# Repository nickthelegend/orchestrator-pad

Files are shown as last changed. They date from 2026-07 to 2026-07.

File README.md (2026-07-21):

<div align="center">

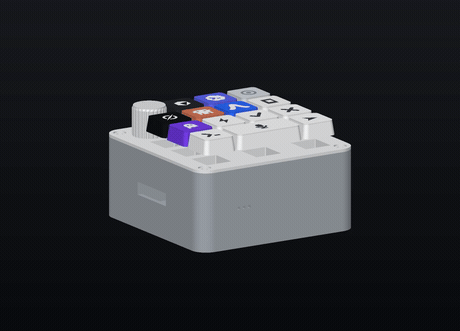
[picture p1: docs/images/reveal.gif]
Orchestrator Pad — assembled, exploding into its layers, and back together


<sub>tray · switch deck · plate · keycaps · knob — [watch the 15s MP4](docs/orchestrator-pad-reveal.mp4)</sub>

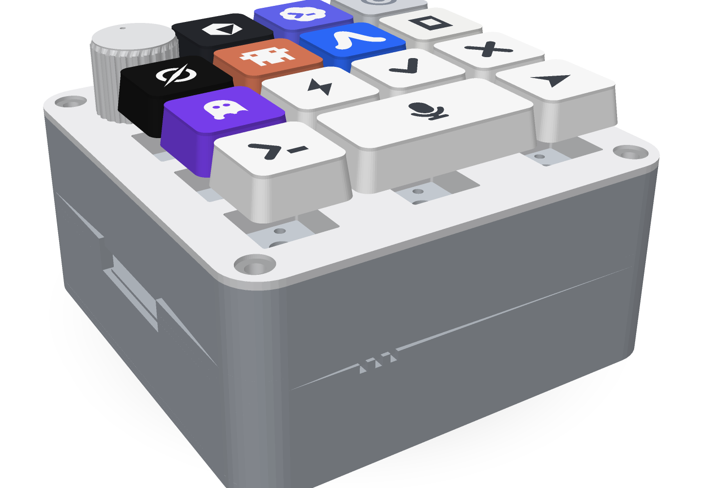
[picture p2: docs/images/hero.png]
Orchestrator Pad — 3D-printed macropad with agent keys, voice bar and effort dial


# Orchestrator Pad

**A desk controller for your coding agents.**
Lock an agent with one key. Hold the bar and talk. Twist the dial to set how hard the model thinks.







[Print it](#print-it) · [What's inside](#whats-inside) · [How a job flows](#how-a-job-flows) · [The CAD is code](#the-cad-is-code) · [Roadmap](#roadmap)

</div>

---

Pointing five different CLI agents at your projects means five terminals and a
lot of retyping. The Orchestrator Pad is a small (~90 × 90 mm) open-source
macropad that turns the routing into muscle memory: **one key per agent, one
bar for your voice, one dial for effort** — from `low` all the way up to
`ultracode`. It speaks Wi-Fi to your orchestrator daemon, with USB-HID as the
fallback.

Everything here is remixable: the enclosure is parametric Python, the agents
on the caps are just a table in `cad/partlib.py`, and the whole thing prints
on a bed-slinger in an evening.

## The deck

<div align="center">
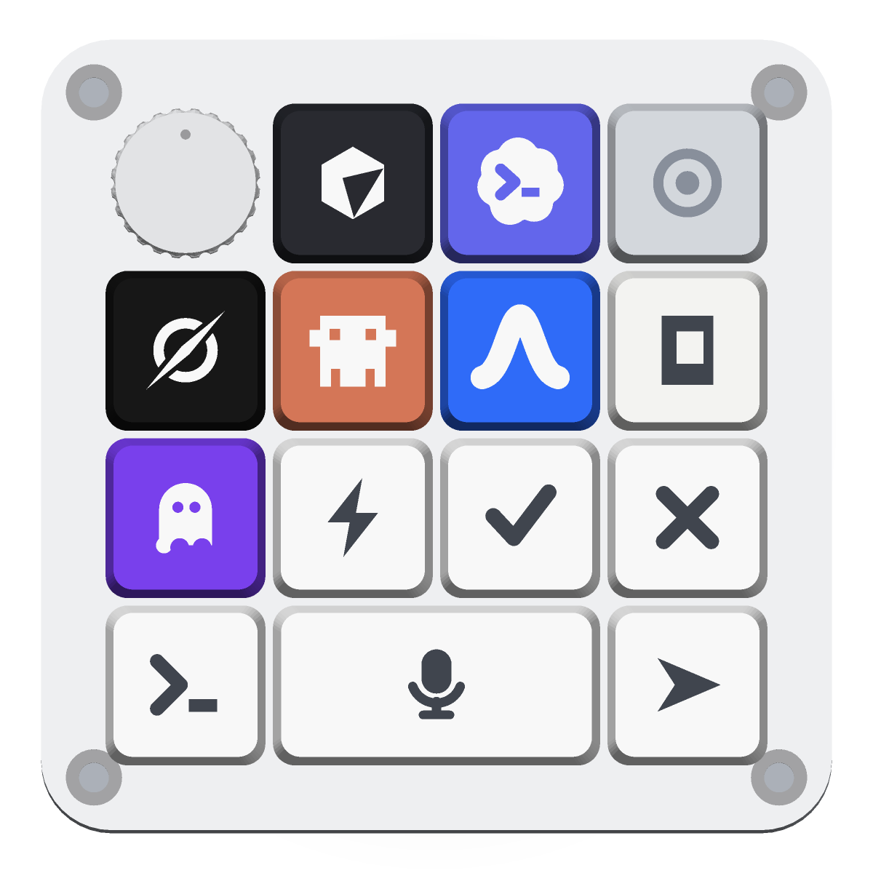
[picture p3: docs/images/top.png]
Top view — key layout

</div>

| | Key | Cap | What it does |
|---|---|---|---|
| 🎛 | **Effort dial** | knurled knob | detents map to `low → medium → high → xhigh → max → ultracode` |
| ⬜ | **Cursor** | cube-facet logo | lock jobs to Cursor |
| 🟣 | **Codex** | cloud `>_` logo | lock jobs to Codex |
| ⚪ | Preset | `◎` | saved context / status (RGB glow optional) |
| ⬛ | **Grok** | circle-slash logo | lock jobs to Grok |
| 🟧 | **Claude Code** | pixel-pal logo | lock jobs to Claude |
| 🟦 | **Antigravity** | arch logo | lock jobs to Antigravity |
| ⬜ | **opencode** | terminal-frame logo | lock jobs to OpenCode |
| 🟪 | **Kiro** | ghost logo | lock jobs to Kiro |
| ⚡ | Run | `⚡` | kick off the queued job |
| ✓ | Approve | `✓` | accept a plan / permission prompt |
| ✕ | Reject | `✕` | decline / cancel |
| ⟩_ | Prompt | `⟩_` | focus the target session's terminal |
| 🎤 | **Voice bar (2u)** | `🎤` | **hold to talk** — audio streams to the daemon for speech-to-text |
| ➤ | Send | `➤` | dispatch to the locked agent at the dialed effort |

Every glyph is debossed 0.6 mm **and** ships with a matching legend infill
piece, so the logos print in a contrast color (white on the colored caps,
charcoal on the white ones) — no more squinting.

## How a job flows

```
hold 🎤 ──► ESP32-S3 streams mic audio ──► daemon does STT
release ──► { agent: "claude", effort: "ultracode", prompt: "..." }
press ➤ ──► daemon routes the job to the locked agent's session
   ✓ / ✕ ──► answer the agent's next approval prompt from the pad
```

The pad itself stays dumb on purpose: it emits a tiny JSON protocol
(`{agent, action, effort, audio?}`) over WebSocket and lets the daemon own
speech-to-text, session routing, and CLI orchestration. Point it at your own
stack by implementing one message handler.

## Make it talk — firmware + backend

The hardware above is the enclosure; these two pieces bring it to life. This
first build is **hold-to-talk over Wi-Fi, no dial** (no potentiometer): press an
agent key to lock that agent, hold the mic key and speak, hear the agent answer.

```
[ pad ]  select agent ─▶ POST /select        [ backend on your Mac ]     [ Loom daemon ]
         hold-to-talk ─▶ POST /voice (PCM) ─▶  STT → agent → TTS  ◀──────▶  handoff + message
              amp     ◀─ 16 kHz PCM reply   ◀─                             (visible in the thread)
```

**Wiring** — the 4×4 matrix, INMP441 mic, and MAX98357A amp + speaker on an ESP32-S3 (full pin-by-pin tables in the [firmware README](firmware/README.md#hardware--wiring)):

<div align="center">
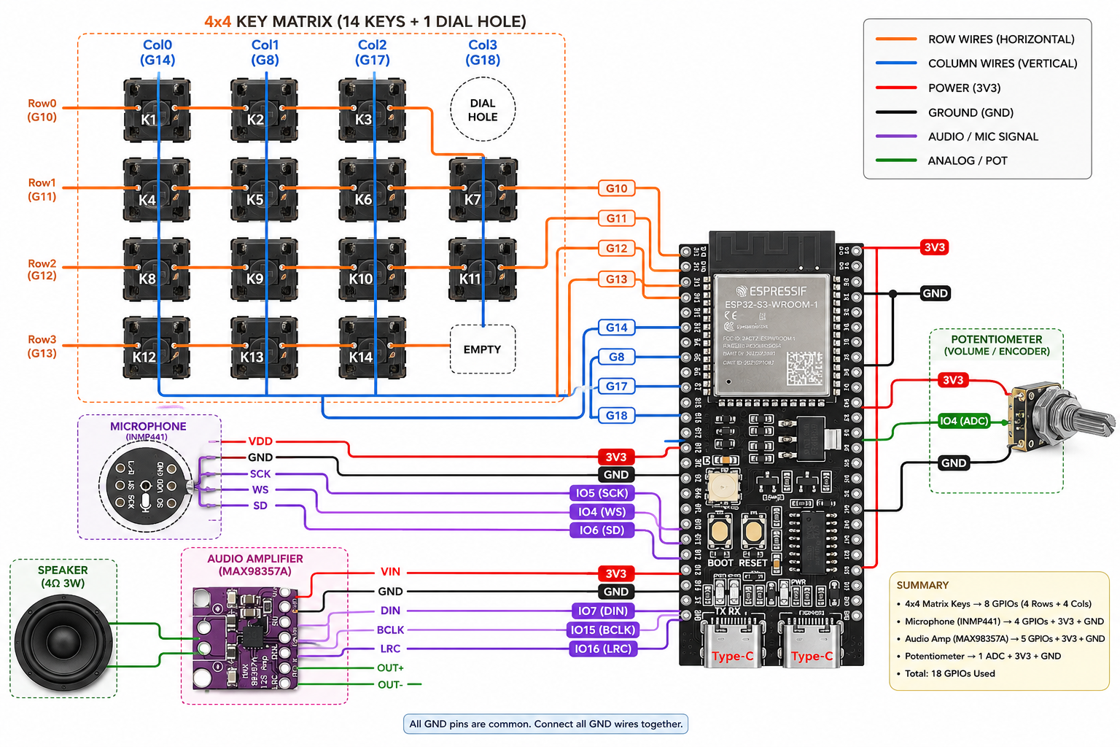
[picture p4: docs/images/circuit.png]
Orchestrator Pad wiring diagram — 4×4 key matrix, INMP441 mic, MAX98357A amp and speaker, on an ESP32-S3-WROOM-1

</div>

- **[`firmware/`](firmware)** — ESP32-S3 sketch: captive-portal Wi-Fi setup
  (`LoomPad-Setup`), agent-select keys, hold-to-talk mic streaming, and a telnet
  debug console. Wiring, key map, and flashing steps in the
  [firmware README](firmware/README.md).
- **[`backend/`](backend)** — a zero-dependency Node server that runs on your Mac
  (Groq STT + LLM, Deepgram TTS) and bridges the pad to the Loom daemon. Two API
  keys, `npm start`, done — see the [backend README](backend/README.md).

**Bring it up:** `cd backend && cp .env.example .env` (add two keys) → `npm start`
→ flash the firmware → join `LoomPad-Setup` and enter your backend URL (a LAN
`http://<mac-ip>:8080`, or a `https://…ts.net` Tailscale Funnel for anywhere) →
press an agent key, hold the mic, talk.

## Print it

<div align="center">
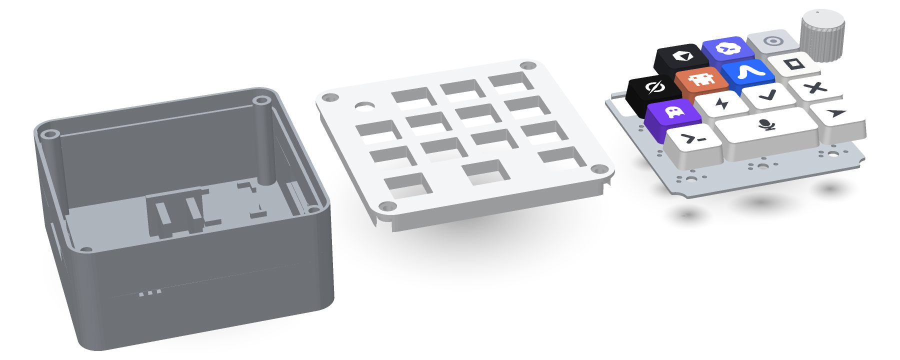
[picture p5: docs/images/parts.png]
Printable parts — tray, plate, keycaps, knob

</div>

| Part | File | Orientation | Supports |
|---|---|---|---|
| Tray (bottom) | [`exports/tray.stl`](exports/tray.stl) | as exported, flat on bed | none |
| Plate (top) | [`exports/plate.stl`](exports/plate.stl) | **flip 180°** — top face on bed | none |
| Switch deck | [`exports/switch-deck.stl`](exports/switch-deck.stl) | as exported, flat on bed | none |
| Keycaps ×14 | [`exports/caps-all.stl`](exports/caps-all.stl) | **flip 180°** — cap tops on bed | none |
| Legend infills ×14 | [`exports/legends-all.stl`](exports/legends-all.stl) | import **with** caps-all, flip together | none |
| Dial knob | [`exports/knob.stl`](exports/knob.stl) | as exported (crown-down) | none |

0.4 mm nozzle · 0.2 mm layers · PETG or PLA. Slow the first layer and outer
walls for crisp glyphs. Each STL is a union of individually watertight
shells — every mainstream slicer merges them automatically.

**Two-color legends:** import `caps-all` + `legends-all` in one plate (they're
pre-aligned), flip 180° together, and assign the legend object a contrast
filament (AMS/MMU). Flipped, the legends are the **first 3 layers on the
bed**, so even a single-extruder printer can do it with one manual filament
swap at layer 4. No multi-color setup? Print caps alone and paint-fill the
recesses — they're 0.6 mm deep on purpose.

**Switch sockets — solder like it's a PCB:**

<div align="center">
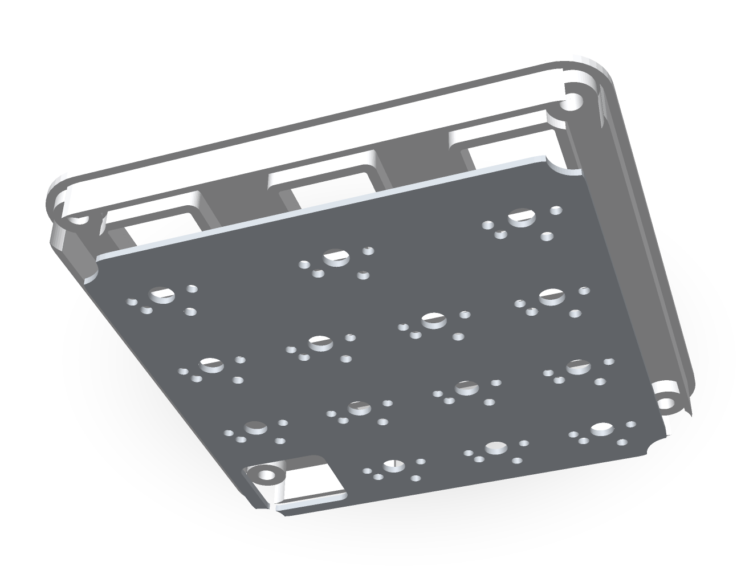
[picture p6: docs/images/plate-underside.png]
Plate underside — donor-keyboard-style switch sockets with MX footprint floors

</div>

Donor-keyboard-style mounting, engineered to print clean: the plate's
underside has a socket well caging every switch body, and the footprints
live on a separate **switch deck** — one flat sheet with all 14 MX clusters
(center-post hole + the two slanted contact holes + 5-pin legs). Because the
deck prints flat on the bed, every hole is perfectly round and the flipped
plate is pure vertical walls — **no bridges, no floating regions, no
supports on either part**.

Assembly: clip the switches into the plate, then press the deck up onto
them from below — it friction-fits on the center posts and 5-pin legs and
seats against the socket-wall rims. The metal pins stick out **2.1 mm**
through the deck: flow solder on, run your matrix wire, done.

**The dial is a mock — it just clips in.** No potentiometer in this build, so
the knob has a snap-fit peg instead of an encoder bore: push it through the
plate's Ø7.4 hole and it clicks under the plate and **spins freely** — a
display dial you can twist for the demo. The plate is unchanged, so it's a
knob-only reprint.

<div align="center">
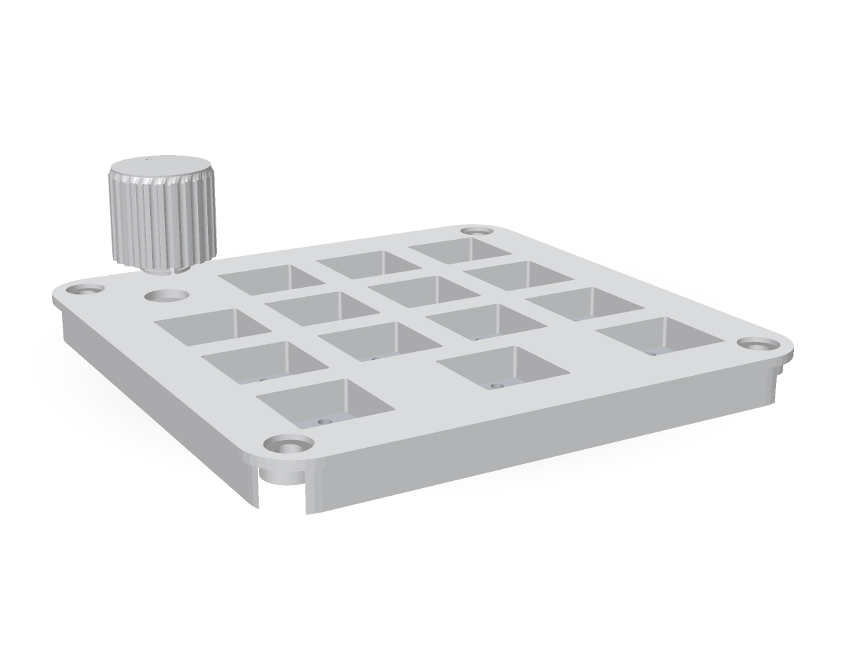
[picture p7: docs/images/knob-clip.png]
Mock knob with snap-fit peg clipping into the plate's dial hole

</div>

Tolerances assume a reasonably tuned printer; every clearance is a named
constant in [`SPEC.md`](SPEC.md) if yours runs tight.

## What's inside

<div align="center">
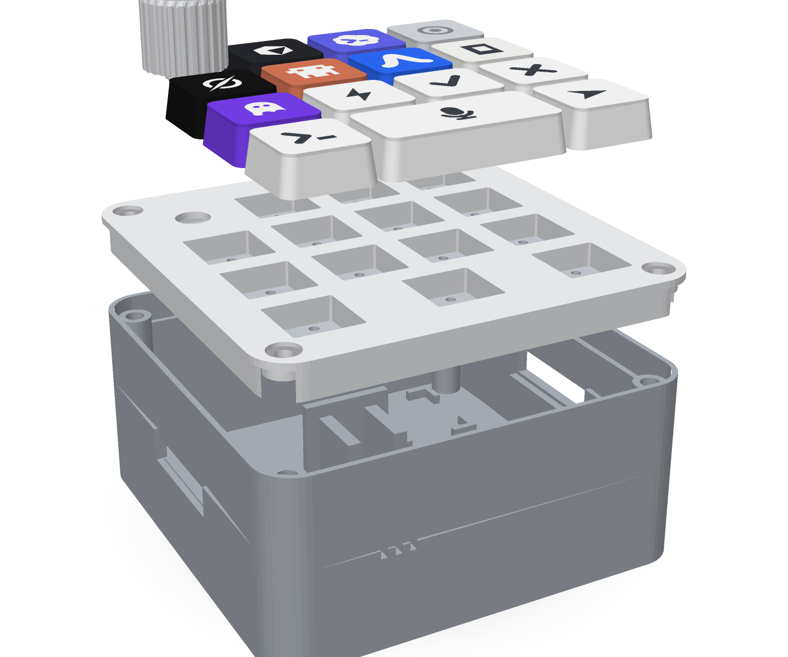
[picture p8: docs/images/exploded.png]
Exploded view

</div>

| Qty | Part | Notes |
|---|---|---|
| 1 | **ESP32-S3 dev board** (WROOM-1, dual USB-C clones welcome) | factory pin headers are fine — the board rides flat shelves + ribs (no posts in the way), with ~24 mm of open headroom above it; install it ports-**right** or ports-**left** (both side walls have a window) |
| 14 | MX-style switches (3-pin plate-mount, donor-board pulls work) | 13 × 1u + 1 for the 2u voice bar; they clip into the plate's square holes exactly like a stock keyboard plate |
| 1 | **4Ω 3W cavity speaker**, flange up to 72 × 42 mm | down-firing bay in the floor: grille slots + 4 × M2.5 self-tapper pilots |
| 1 | **MAX98357A I2S amp** breakout | drops into the corner pocket, foam-tape mounted |
| 1 | I2S MEMS microphone (INMP441 class, round or square) | glues behind the front mic grille |
| 1 | EC11 rotary encoder | M7 bush mounts in the plate; 15 mm D-shaft; the knob hides the nut |
| 4 | M3 heat-set inserts + **M3×8** button-head screws | tray bosses ← plate counterbores |
| 4 | rubber feet, **≥3 mm tall** | give the down-firing speaker its air gap |
| — | zip ties, jumper wires | a flat wire bar with zip-tie slots is printed into the tray (no posts in the way) |
| — | optional: WS2812 LEDs | under the preset key |

<div align="center">
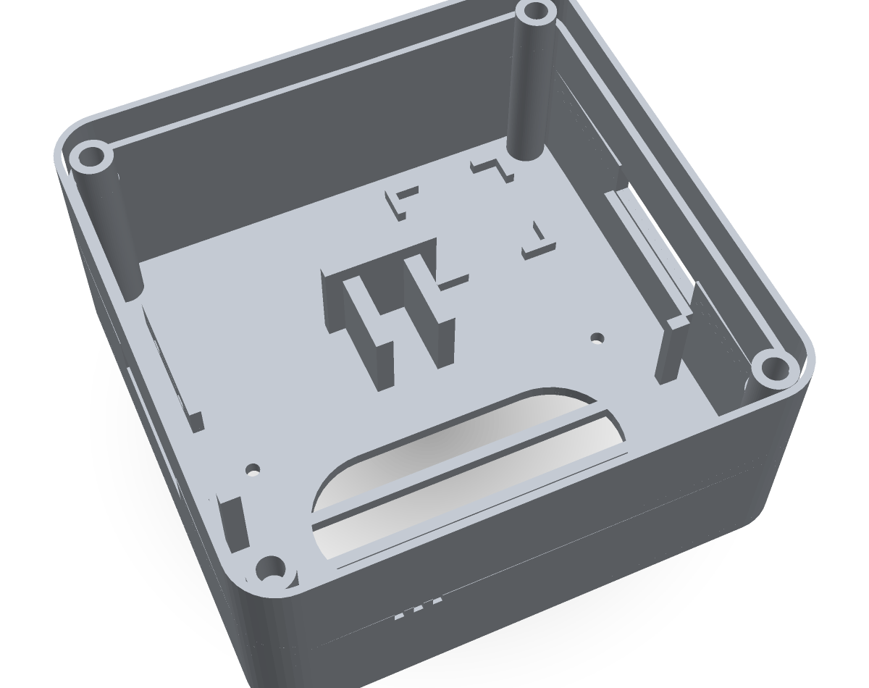
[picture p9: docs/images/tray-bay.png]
Tray interior — reversible board bay, speaker grille, amp pocket, wire posts

</div>

**Cable exits either side.** The board lies across the case with its USB-C
edge against a side wall, and both side walls carry a window — so you install
it **ports-right or ports-left** depending on which way your desk wants the
cable. The unused window becomes a wire pass-through for the speaker or amp
harness.

Assembly: heat-set the four inserts, screw the speaker over the floor grille,
foam-tape the amp into its pocket, rest the board on the shelves + ribs
(components up, USB out whichever side window you picked), clip the switches into the plate,
hand-wire the matrix, glue the mic behind the grille, zip-tie the slack to the
posts, screw the sandwich together, press on caps and knob. A strip of kapton
over the board is cheap insurance under the switch pins.

## The CAD is code

No STEP files, no Fusion — the entire enclosure is generated by
[`cad/partlib.py`](cad/partlib.py), a ~500-line kernel that extrudes 2D
`shapely` profiles into watertight shells (**zero 3D CSG**, so there's nothing
to corrupt), plus one script per part. Change a constant, rerun, reprint:

```bash
python3 -m venv .venv && .venv/bin/pip install numpy shapely
cd cad
../.venv/bin/python assembly.py      # STLs + GLBs + MANIFEST.json
../.venv/bin/python render_docs.py   # re-render the README images (numpy only)
```

<details>
<summary><b>Design notes & receipts</b></summary>

- Every part is validated for closed, manifold, positive-volume shells on
  every build (`partlib.validate`) — the manifest records the results.
- The fit audits in `cad/audit_*.py` are re-runnable: they check switch
  cutouts, screw stacks, cap clearances, and the DevKitC seating against
  **Espressif's official board drawing** — which is how we caught that the
  DevKitC-1's USB ports sit 7.79 mm off the board centerline. The case slot
  is centered on the *native/OTG* port, not the board.
- Keycaps use a hollow tapered loft with a printed MX cross stem and 0.6 mm
  debossed glyphs built as layered shells — no boolean subtraction anywhere.
- `exports/orchestrator-pad-assembled.glb` and `-exploded.glb` are the full
  colored models — drop them into any glTF viewer.

</details>

## Roadmap

- [x] v1 printable enclosure, caps, knob — parametric CAD + audited fit (branch [`v1`](../../tree/v1))
- [x] v2 logo keycaps (Claude Code · Antigravity · opencode · Kiro · Cursor), taller case for full DevKitC clearance, USB mating relief (branch [`v2`](../../tree/v2))
- [x] v3 — Grok + Codex keys (seven agents), two-color legend infills (`legends-all.stl`) (branch [`v3`](../../tree/v3))
- [x] v4 — the fat base: 28 mm component bay with a down-firing speaker bay, amp pocket, board bridge with header-pin clearance, dual-USB-C window, and zip-tie wire posts
- [x] v5 — donor-style switch sockets + the flat-printed **switch deck** (footprint sheet, pins protrude 2.1 mm for direct soldering; zero bridges/supports on the plate) (branch [`v5`](../../tree/v5))
- [x] v6 — USB moved to the **side walls**: the board bay is rotated and reversible, so the cable exits right or left (branch [`v6`](../../tree/v6))
- [x] **v7 (current)** — **fatter**: 40 mm case with ~24 mm of open headroom above the board, and the cylindrical locator/wire posts replaced with flat guide rails + zip-tie slots (nothing free-standing in the bay)
- [ ] `firmware/` — ESP-IDF: matrix scan, encoder detents, hold-to-talk ring
      buffer, WebSocket client, USB-HID fallback
- [ ] daemon reference handler + pairing flow
- [ ] hand-wire guide with photos
- [ ] PCB with hotswap sockets + WS2812
- [ ] translucent-PETG preset keys with light pipes

PRs welcome — the fastest way to help is to print one and file issues with
your tolerance notes.

## License

[MIT](LICENSE). The agent names and logo-inspired cap glyphs refer to
third-party projects — the marks belong to their respective owners; the
glyphs here are simplified geometric homages for personal builds.

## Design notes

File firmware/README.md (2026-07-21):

# Orchestrator Pad — firmware

ESP32-S3 firmware for the hold-to-talk build. Select an agent with a key, hold
the mic key and talk, hear the agent answer — all over Wi-Fi to the
[backend](../backend) on your Mac. Wi-Fi and the backend address are set once
through a captive portal and remembered in flash; **no recompile to change
networks**, and **no potentiometer on this build** (the effort dial is omitted).

Sketch: [`orchestrator_pad/orchestrator_pad.ino`](orchestrator_pad/orchestrator_pad.ino).

## What it does

1. **Provision** — first boot (or hold **K1** at power-on) raises a Wi-Fi
   access point, **`LoomPad-Setup`**. Join it from a phone/laptop; a captive
   page lists nearby networks and asks for the **backend URL** and a **pad
   token**. Save → the pad joins your Wi-Fi and stores everything in NVS.
2. **Connect** — it starts a telnet debug server, checks the backend's
   `/health`, and asks the backend to **speak "connected"** through the amp.
3. **Run** — an agent key locks that agent in Loom (a handoff, visible in the
   thread) and lights the LED its colour. Hold **K1** to record; release to send
   the audio to that agent and play its spoken reply.

## Hardware & wiring

ESP32-S3-DevKitC-1 (N16R8 — 16 MB flash / 8 MB PSRAM). No pot, no diodes.

<div align="center">
Orchestrator Pad wiring diagram — 4×4 key matrix, INMP441 mic, MAX98357A amp + speaker, on an ESP32-S3-WROOM-1
</div>

The full wiring at a glance: the 4×4 matrix (rows `G10–G13`, columns
`G14/G8/G17/G18`), the INMP441 mic and MAX98357A amp on I2S, and the (optional)
pot. The tables below are the same thing, cell by cell — all grounds are common.

**Mic — INMP441 (I2S RX):** `VDD→3V3`, `GND→GND`, `L/R→GND`

| INMP441 | SCK | WS | SD |
|---|---|---|---|
| GPIO | **5** | **4** | **6** |

**Amp — MAX98357A (I2S TX):** `Vin→3V3`, `GND→GND`, `SD→3V3` (leave SD high to enable)

| MAX98357A | BCLK | LRC | DIN |
|---|---|---|---|
| GPIO | **15** | **16** | **7** |

**4×4 key matrix** (rows are `INPUT_PULLUP`, columns driven low one at a time —
no diodes needed):

| | Col0 | Col1 | Col2 | Col3 |
|---|---|---|---|---|
| **Rows →** | GPIO 14 | GPIO 8 | GPIO 17 | GPIO 18 |
| Row0 · GPIO 10 | **K1 mic** | K2 | K3 | — |
| Row1 · GPIO 11 | K4 | K5 | K6 | K7 |
| Row2 · GPIO 12 | K8 | K9 | K10 | K11 |
| Row3 · GPIO 13 | K12 | K13 | K14 | — |

**Status LED:** onboard WS2812 on **GPIO 48**.

All pins live in [`orchestrator_pad/config.h`](orchestrator_pad/config.h) — change
them there if your wiring differs.

## Key map

Edit [`orchestrator_pad/agents.h`](orchestrator_pad/agents.h) to match your
keycaps. As shipped:

| Key | Role | Agent | LED |
|---|---|---|---|
| **K1** | 🎤 hold to talk | — | red while recording |
| K2 | agent | `claude-code` | amber |
| K3 | agent | `opencode` | teal |
| K4 | agent | `codex` | green |
| K5 | agent | `grok-code` | white |
| K6 | agent | `antigravity` | blue |
| K7 | agent | `kiro` | purple |

K8–K14 are spare. K1 doubles as the **re-provision** key: hold it at power-on to
wipe saved Wi-Fi and re-open the portal.

### Status-LED colours

| Colour | Meaning |
|---|---|
| blue | booting |
| cyan / magenta | connecting / setup portal open |
| green | connected & ready |
| agent colour | that agent is selected (idle) |
| red | recording (or an error) |
| amber | thinking (waiting on the reply) |

## Flashing

**Libraries** (Arduino IDE → Library Manager):

- **WiFiManager** by *tzapu* — the captive portal.
- `ESP_I2S`, `WiFi`, `HTTPClient`, `Preferences` ship with the **arduino-esp32
  core 3.x** — nothing to install, but you do need core 3.x (Boards Manager →
  "esp32" by Espressif, ≥ 3.0).

**Board settings** (Tools menu) — the three starred ones matter:

- Board: **ESP32S3 Dev Module**
- ⭐ **PSRAM: `OPI PSRAM`** — the record buffer is `ps_malloc`'d; without this it
  fails to allocate and the mic won't record.
- ⭐ **USB CDC On Boot: `Enabled`** — so the Serial monitor works over USB-C.
- ⭐ **Partition Scheme: `Huge APP (3MB No OTA/1MB SPIFFS)`** — the TLS stack
  pushes the build to ~90 % of the *default* 1.3 MB app partition (it fits, but
  barely). Huge APP drops it to ~37 %. Flash Size: `16MB`.

> Verified: this compiles clean against **esp32 core 3.3.10 + WiFiManager 2.0.17**
> for `esp32s3` (OPI PSRAM, USB-CDC) — 1.18 MB flash, 48 KB RAM, no warnings in
> the sketch.

**Steps:**

1. Open [`orchestrator_pad/orchestrator_pad.ino`](orchestrator_pad/orchestrator_pad.ino).
2. Install WiFiManager, set the board options above, pick the port, **Upload**.
3. First boot: join the **`LoomPad-Setup`** Wi-Fi from your phone. If the portal
   doesn't pop up, browse to `http://192.168.4.1`.
4. Pick your Wi-Fi, enter the **backend URL** and **pad token** (below), save.
5. It joins, says "connected," and you're ready: **press an agent key, then hold
   K1 to talk.**

### Backend URL & token

One field decides where — and how — the pad reaches the backend; the **scheme
picks the transport**:

| You're… | Enter | Token |
|---|---|---|
| on the same Wi-Fi as the Mac | `http://<mac-lan-ip>:8080` (e.g. `http://192.168.1.20:8080`) | blank is fine on a trusted LAN |
| anywhere / the pad moves around | `https://<machine>.<tailnet>.ts.net` (Tailscale Funnel) | **required** — Funnel is public |

- **`http://…`** → plain connection. Use the Mac's **LAN IP**, *not* its
  `tailscale ip` (`100.x`) — a bare ESP32 can't route to a tailnet address.
- **`https://…ts.net`** → TLS, with the Let's Encrypt root pinned (the pad
  verifies the cert, so the token can't be MITM'd). Set the same `PAD_TOKEN` on
  the backend. See the [backend README](../backend/README.md#pointing-the-pad-at-it)
  for the one-time `tailscale funnel 8080` setup.

Change either later without reflashing: `reset-wifi` over telnet (or hold **K1**
at power-on) re-opens the portal.

## Telnet debug

The S3's USB-CDC serial can be flaky, so the pad mirrors its logs to a telnet
server and takes commands back — no cable needed:

```
telnet <pad-ip> 23
```

| Command | Does |
|---|---|
| `help` | list commands |
| `status` | Wi-Fi / IP / RSSI / heap / PSRAM / backend / selected agent |
| `ip` · `heap` · `agent` | quick reads |
| `select <agent>` | lock an agent (same as pressing its key) |
| `say <text>` | speak text through the amp (tests the backend + amp) |
| `talk` | hands-free: record ~4 s and send (tests the mic without a key) |
| `reset-wifi` | wipe Wi-Fi + settings and reboot into the portal |
| `reboot` | restart |

`say hello` and `talk` are the fastest way to prove the audio path end to end.

## Troubleshooting

| Symptom | Fix |
|---|---|
| No serial output | Set **USB CDC On Boot: Enabled**, re-upload |
| "PSRAM alloc failed" in the log | Set **PSRAM: OPI PSRAM** |
| "backend not reachable" | Backend running? Right URL? On `http://`, use the Mac's **LAN IP** not `100.x`. Fix with `reset-wifi` |
| Works on LAN, fails on the `ts.net` URL | Is `tailscale funnel` running? Does `PAD_TOKEN` match on both sides? (a 401 means the token's wrong/blank) |
| Portal never opens | Forget/rejoin `LoomPad-Setup`, or browse to `192.168.4.1` |
| Amp silent | Check `DIN/BCLK/LRC` wiring and that the amp's **SD pin is tied to 3V3** |
| Mic captures nothing | Check `SCK/WS/SD`, and tie the INMP441 **L/R pin to GND** |
| Keys wrong / swapped | Fix the pin arrays in `config.h` and the grid in `agents.h` |

See the [backend README](../backend) for the server it talks to.

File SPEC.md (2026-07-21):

# Orchestrator Pad — dimensional spec (v7)

Open-source ESP32 macropad for orchestrating coding agents: lock a target agent
(Grok / Codex / Claude Code / Antigravity / opencode / Kiro / Cursor),
hold-to-talk voice capture, and a dial that sets model effort
(`low → medium → high → xhigh → max → ultracode`).

All dimensions in **mm**. Axes: X right, Y back (away from user), Z up.
Origin: center of the case footprint, Z=0 at the tray's outer bottom face.

## Layout (19.05 mm grid, 4 columns x 4 rows)

Column centers X: -28.575, -9.525, +9.525, +28.575 (cols 0..3)
Row centers Y: +28.575, +9.525, -9.525, -28.575 (rows 0..3, row 0 = back/top)

| Pos | What | Glyph (debossed) |
|---|---|---|
| r0c0 | EC11 rotary encoder (effort dial) | knurled knob, tick dot |
| r0c1 | agent key: Cursor | `cursor` (cube, raised facet) |
| r0c2 | agent key: Codex | `codex` (cloud, raised `>_`) |
| r0c3 | preset/status key (translucent look) | `target` |
| r1c0..c3 | agent keys: Grok, Claude Code, Antigravity, opencode | `grok` (circle-slash), `claude` (pixel-pal), `antigravity` (arch), `opencode` (frame) |
| r2c0 | agent key: Kiro | `kiro` (ghost) |
| r2c1..c3 | run / approve / reject | `bolt`, `check`, `cross` |
| r3c0 | prompt/terminal key | `prompt` |
| r3 c1–c2 | **voice bar, 2u** (hold-to-talk), centered at X=0 | `mic` |
| r3c3 | send/dispatch key | `send` |

Total: **14 MX switches** (13 x 1u + 1 x 2u), 1 EC11 encoder.

## Case (two printed shells + knob + caps)

### Tray (bottom shell) — `part_tray.py`
- Outer: 90.0 x 90.0, corner R8, height **40.0** (v7 fat/tall base — +12 over
  v6's 28.0, for lots of open headroom above the board; the interior is a
  component bay). Wall 2.4, floor 2.4.
- Ledge for the top's skirt: below Z=33.5 wall is 2.4 thick; above Z=33.5 the
  inner face steps out so wall is **1.2** thick (skirt seat).
- 4 corner bosses Ø7.0 at (±39, ±39) — **round** (M3 heat-set inserts thread
  in): solid pedestal from floor top (Z2.4) to **Z=31.5**, insert ring
  Ø7.0/Ø4.0 to **Z=37.5** (bore 6.0 deep from the top, floor at Z 31.5 — M3
  heat-set insert). The bosses now run floor→37.5 (through the raised ledge).
- **USB windows**, BOTH side walls (X=+45 and X=-45): each **26.0 wide** in
  Y centered Y=0, **Z 17.0..23.5**, through BOTH wall columns. The board
  turns 90° so its ports face a side wall, and the bay is **reversible** —
  the board installs **ports-right or ports-left**, and the *unused* window
  is documented as a **wire pass-through** (run the speaker/mic/amp harness
  or a USB extension out of it). The board's dual side-by-side USB-C ports
  sit on its TOP face (shells 8.94 x 3.3 → Z 17.6..20.9, center 19.25) and
  exit through whichever window they face; each window is wide + tall enough
  that exact port offsets don't matter (shells stay inside for port centers
  |y| ≤ 8.53, a 12-wide plug hood for |y| ≤ 7.0), and the receptacle face
  sits only ~1.7 behind the outer wall — under the ~2.5 of exposed plug
  shroud, so any hood works at the aperture mouth. v7 raised the ledge to
  33.5, so each window top (23.5) now sits **entirely below the ledge** —
  both wall columns close the window with a solid cap at 23.5 and run solid
  to their tops (liner→33.5, outer→40.0), and the **plate skirt no longer
  needs a USB notch**. The two side cuts split each cut wall band into a back
  arc and a front arc — every piece is still its own watertight prism, fused
  to the solid ring bands above and below by the 0.2 lap.
- **Board bay (rotated + REVERSIBLE)** — dual-USB-C ESP32-S3 clone,
  components UP, factory header pins DOWN, laid **along X**: up to **64.0
  long (X) x 30.0 wide (Y)**, centered Y=0 (|y| ≤ 15). Two installs, both
  seating identically because every bay feature is mirror-symmetric about
  X=0:
  - **ports-right** X **-22.0 … +42.0** (USB-C exits the X=+45 window)
  - **ports-left**  X **-42.0 … +22.0** (USB-C exits the X=-45 window)
  - side shelves (BOTH walls): tabs protruding 1.6 from each side wall's
    inner face (42.6), spanning **|x| 41.0..42.8** (0.2 lap into the liner)
    and **|y| ≤ 14.0**, body Z 13.5..16.0 — the board's port edge seats on
    one and its far edge overhangs the other; **Z=16.0** top faces (1.0
    bearing, 0.6 edge-to-wall gap on the port side).
  - mid-span ribs: two walls at **X +4.0..+7.0** and **X -7.0..-4.0**,
    **Y +1.0..+16.0**, floor to **Z=16.0** — they carry the board's middle
    (~112 mm² of total seat bearing per orientation). They stay at Y ≥ +1.0
    on purpose: the speaker flange occupies X ±36, Y -42..0, and a rib
    crossing it would foul the flange (1.0 clear as drawn).
  - **board cage (FLAT — NO cylindrical posts, v7)**: the board is caged in
    Y by flat guide walls only, placed only in speaker-clear zones (the
    flange is X ±36, Y -42..0; supports live at Y>0 or |X|>36). Inner faces
    at |y| = 15.1 → 0.1 clearance per side to a 30-wide board, tops **Z=19.0**
    (1.4 lip over the board top at 17.6). Mirror-symmetric about X=0:
    - **back guide rail**: a flat wall, inner face **Y=+15.1**, outer
      **Y=+17.1** (2.0 thick), spanning **X -10.0..+10.0**, floor→Z=19.0 —
      caps the board's +Y edge. (Nominal span was X ±34, but the amp
      L-ridges reach X 10.5 inside the rail's Y band 15.1..17.1, so the rail
      is trimmed to **±10.0** to clear the amp by 0.5 while staying
      symmetric and watertight; it fuses with the two mid-span ribs at
      Y 15.1..16 by design, tying it to the load-bearing ribs.)
    - **front corner tabs**: two flat tabs, inner face **Y=-15.1**, outer
      **Y=-17.1**, spanning **X 36.8..40.0** and **X -40.0..-36.8** (both at
      |X|>36, clear of the flange edge at 36 by 0.8), floor→Z=19.0 — they
      guide the board's front-edge corners in whichever orientation reaches
      that side.
    Together with the flat mid-span ribs and dual side shelves (all
    retained, unchanged), the board is caged in Y from both edges while
    nothing ever crosses the speaker flange.
  - under-board clearance floor→16.0 = **13.6 mm** for the soldered header
    pins (~8.5 under the PCB) + angled dupont connectors. Headers now run
    along the board's long edges (y = ±15). Wire in the open pockets either
    side of the ribs. Pin tails that land over a rib (X ±4..7, Y +1..+16)
    must be clipped flush; over the speaker zone (Y < 0) the driver bump can
    rise to Z 14.9 under the pin rows — clip there too, or verify your
    speaker's bump footprint. (Headers usually stop ~2 mm short of the
    board ends, clearing the 1.0 shelf lip.)
- **Speaker bay** (down-firing, flange ON the floor, centered (0, -21)):
  - floor opening: racetrack (rounded-rect R12) **54 x 24** at (0, -21) with
    two 2.0-wide grille bars along X → 3 slots (~6.7 each), through both
    floor layers.
  - 4 screw pilots Ø2.4 THROUGH the floor at (±31.5, -37.5) and
    (±31.5, -4.5) — the 63 x 33 pattern. M2.5 x 6 self-tappers from inside:
    heads on the flange, tips end 2.1 under the floor, inside the ≥3 mm
    foot gap. The two back pilots' bottom rims merge ~1.0 into the front
    feet-recess rims (0.6 recess layer only) — stick those feet biased
    outward.
  - fits flanges up to **72 x 42** (a sharp-cornered 72 x 42 grazes the two
    front bosses by ~0.5; real cavity flanges with corner R ≥ 6.5 clear —
    **measure yours**) and driver bumps up to **Ø50 x 11 tall** (oval, ≤
    50 x 40 in plan): bump top 2.4 + 1.5 + 11 = **14.9** clears the board
    underside at 16.0 by 1.1. **Measure the bump height — the bay assumes
    ≤ 11.**
- **Amp pocket**: four L-corner ridges (1.5 wide, 2.0 tall, 6-long legs)
  framing a 20 x 20 pocket centered **(+22, +27)** — the MAX98357A drops in,
  foam-tape mounted. It sits on the back strip, out from under the rotated
  board: the ridges span X 10.5..33.5, Y 15.5..38.5, so the outer edge clears
  the board edge at Y 15.0 by **0.5** (both orientations), the corner bosses'
  inner face at X 35.5 by **2.0**, and the speaker by 15.5. v7 deleted the
  locator posts, so the pocket is now a **clean, full 20 x 20** (the old
  (+20, +17.6) post no longer clips its south edge); an ~18 x 16 breakout
  drops in with ~1.0/side play. The nearest cage wall is the back rail,
  trimmed to ±10 so it clears the amp by 0.5.
- **Wire bar** (FLAT — replaces the v6 wire posts, NO cylinders): a low flat
  wall along the west interior, inner face **X=-36.0**, outer **X=-38.0**
  (2.0 thick), spanning **Y +6.0..+30.0**, floor→**Z=8.0**, with **two
  3.2-wide x 2.0-tall through-slots** (band-split in Z, at Z 3.0..5.0)
  centered **Y=+12** and **Y=+24**. A zip tie threads a slot and cinches the
  harness against the bar. It tops out at Z 8.0 — well below the left USB
  window (Z 17.0) — and Y 6..30 clears the speaker flange (Y≤0) by 6.0 and
  the (-39, +39) corner boss by 5.5. It underlies the ports-left board
  footprint in plan but sits 8.0 below the board underside (16.0), so it
  never obstructs board seating in either orientation.
- **Mic grille**, front wall (Y=-45): 3 x 1.5 square ports, spacing 3.0,
  centered X=-20, **Z 19.4..20.9** — far below the raised 33.5 ledge; the round
  I2S mic module glues behind them, above the speaker body. (Replaces v3's
  low-Z round ports.)
- Feet recesses: bottom face, 4 x Ø9.0 x 0.6 deep at (±36, ±36). Use
  **≥3 mm tall feet** so the down-firing speaker breathes (and the M2.5
  tips stay 0.3 off the desk).

### Top plate — `part_plate.py`
- Plate: 90.0 x 90.0, R8, **1.5 thick**, spans Z 40.0 → 41.5 (counterbore
  bands 40.0..40.7 + 40.5..41.5; case stack ~41.5 mm + caps/knob).
- 14 MX cutouts **14.1 x 14.1** (14.0 nominal + 0.1 print tolerance) at the
  grid positions above (2u voice = one switch centered at X=0, r3). These
  are exactly donor-keyboard-style plate holes — harvested 3-pin white MX
  clones clip straight into the 1.5 plate.
- **Switch sockets + deck (v5.1, donor-board style, print-clean)**: under
  every cutout a pocket box cages the switch body — walls 1.6 (outer 17.3
  sq) from **Z 36.5** (the MX base-seat plane, plate top − 5.0) up 0.2 into
  the plate. Flipped for printing, the plate is pure vertical walls: no
  bridges, no floating regions, no supports. The footprint floor is the
  separate **switch deck**: a 1.2-thick flat sheet (78 × 78 R6, Z
  35.3..36.5) carrying all 14 MX clusters — center post Ø**4.15** (snug on
  the Ø4.0 post), contact pin holes Ø**2.0** at (−3.81, +2.54) and
  (+2.54, +5.08), 5-pin leg holes Ø**1.85** (snug on Ø1.7) at (±5.08, 0);
  offsets from each key center, +Y toward the back. It prints FLAT
  (perfect holes), presses onto the switch posts/legs from below
  (friction-fit), seats against the socket-wall rims, has a 16 sq cutout
  under the EC11 body and Ø8.8 notches at the four screw towers (≥0.15,
  audited). The metal pins protrude **2.1** below the deck (tips Z 33.2):
  solder the matrix wires directly to them, PCB-style.
- Knob hole Ø**7.4** at r0c0 (EC11 M7 threaded bush).
- Skirt: ring 1.15 thick x 6.7 deep (Z 33.5 → 40.2), outer profile =
  87.3 x 87.3 R6.9 x-y, inner 85.0 x 85.0 R6.3 (drops inside the tray's
  87.6 upper 1.2 wall with ~0.15 clearance per side). Notched ONLY for the
  bosses now: **Ø8.6 corner clearances** at (±39, ±39) around the tray
  bosses (which rise to Z 37.5, through the skirt band). v7 raised the ledge
  to 33.5 while the USB windows still top out at 23.5 — the **side windows
  sit entirely below the ledge**, no longer cross into the skirt seat, so the
  **v6 side USB notches are gone**. The ring survives as **4 arc segments**
  (one per edge, severed at the 4 corner notches), each a watertight prism
  fused to plate band A. (The front mic notch is likewise unneeded: the mic
  grille at Z 19.4..20.9 sits far below the ledge.)
- 4 screw towers Ø7.6 from Z 37.5 → 40.2 at (±39, ±39), through-hole Ø3.4
  continuing through the plate, counterbore Ø6.4 x 0.8 from the top face
  (M3 x 8 button-head into the tray inserts).

### Keycaps — `part_caps.py`
- 1u: base 18.2 x 18.2 R2.5, top 16.4 x 16.4 R2.2, height **7.5** (loft taper),
  wall 1.6, hollow underneath.
- 2u voice bar: base 37.25 x 18.2, top 35.4 x 16.4, same height/wall.
- MX stem: post Ø5.8, length 3.9 below the cap ceiling; cross slots
  4.15 x 1.35, depth 3.9 (friction fit on MX stem).
- Glyphs debossed **0.6** into the top: build the top 0.8 mm of the cap as a
  layer with glyph-shaped holes; solid body below ends 0.6 lower, glyph
  islands (e.g. the pixel-pal's eyes) overlap 0.2 into the body below so every
  shell fuses when sliced.
- **Legend infills**: each glyph also exports as a separate flush 0.6 prism
  (`<id>-legend` items, merged into `exports/legends-all.stl`, same drop as
  `caps-all.stl` so both stay aligned). Print caps + legends together in two
  colors (AMS/MMU, or a manual filament swap on the last 3 layers when caps
  print top-face-down), or skip the file and paint-fill the recesses. Legend
  colors per key live in `partlib.key_layout()` (white on colored caps, dark
  gray on white caps).

### Knob — `part_knob.py` (v7.1 MOCK, no potentiometer)
- Ø17.0, height 15.0. Knurl: 24 flutes (Ø1.6 scallops on the rim).
- Top: 1.5 chamfer loft to Ø16.0, tick-dot deboss near edge.
- **Snap-fit peg** on the underside — no EC11 shaft: a Ø**7.2** tube split by
  1.2-wide cross-slots into 4 flex fingers, hollow Ø4.6 core, with a Ø**8.2**
  barb at the tip and a stepped lead-in chamfer. Push it through the plate's
  Ø7.4 hole: the fingers compress, the barb springs out under the plate. The
  knob body rests on the plate top (Z 41.5) and the barb catches the
  underside (ledge Z 39.8, **0.2 axial play** below the plate bottom) so it
  stays on **and spins freely** — a display dial for the demo. The plate is
  identical to an EC11 build; only this part differs. **Tuning:** if the snap
  is too tight, drop `BARB_D` to 8.0; too loose, raise to 8.4.
- Prints **crown-DOWN** (peg pointing up) — no supports.

## Assembly (`assembly.py`)
- Tray at Z0 → plate on top (plate top face Z=41.5).
- Caps: bottom face at **Z=47.0** (switch seated, cap floats ~5.5 over plate).
- Knob: bottom at **Z=41.5** over r0c0 (rests on the plate top; snap peg
  clips through the Ø7.4 hole and spins).
- Exports: `exports/orchestrator-pad-assembled.glb`, `exports/orchestrator-pad-exploded.glb`
  (tray +0 / plate +20 / caps +40 / knob +52), plus one STL per printable part
  (`tray`, `plate`, `caps-all`, `legends-all`, `knob`).

## Colors (GLB preview only)
tray `#AEB4BC`, plate `#F4F5F7`, preset cap `#D8DCE2`, Grok `#141414`,
Codex `#6366F1`, Claude Code `#D97757`, Antigravity `#2D6BFF`,
opencode `#FAFAF8`, Kiro `#7A3FF2`, Cursor `#26282E`,
run/approve/reject/prompt/send `#FFFFFF`, voice bar `#FFFFFF`, knob `#E8E9EB`.
Legends: white `#FFFFFF` on colored caps, dark `#3F444D` on white caps,
mid `#8A919E` on the preset.

Logo glyphs (`grok`, `codex`, `claude`, `antigravity`, `opencode`, `kiro`,
`cursor`) are simplified geometric homages debossed 0.6 into the caps; the
original marks belong to their respective projects.

## BOM (v7)
Dual-USB-C ESP32-S3 clone board **with factory pin headers** (pins DOWN,
components + USB-C on TOP — the 13.6 under-board bay swallows the ~8.5 pin
tails; v3's headerless rule is gone). **Fit it sideways**: the board lies
along X with its ports facing a side wall, and you choose **ports-right or
ports-left** at assembly time — the bay is symmetric, so both drop in the
same way. Also: MAX98357A I2S amp breakout, 4Ω 3W
cavity speaker (flange ≤ 72 x 42, driver bump ≤ 11 tall — **measure it**)
+ 4 x **M2.5x6** self-tappers, round I2S mic module (INMP441-class),
**no potentiometer** (this build is hold-to-talk; the knob is a mock display
dial that snaps into the plate — omit the EC11), 14 x MX-style switches (donor-harvested
3-pin white MX clones fine), 4 x M3 heat-set inserts + **M3x8** button-head
screws (unchanged in v7: head bears at Z 40.7 under the counterbore, tip at
Z 32.7 vs the bore floor 31.5 — margin **+1.2**, and it still reaches the
insert zone; an M3x10 would bottom out in the Ø4.0 x 6.0 boss bore 0.8
before the head clamps), 4 x rubber feet Ø8 **≥3 mm tall** (down-firing
speaker + screw-tip clearance), zip ties for the wire bar, jumper wires.
Optional: WS2812 under the preset keys.

## Print notes
0.4 nozzle, 0.2 layers, PETG or PLA. Tray + plate flat side down, no
supports (the **two** 26 mm bridges over the side USB windows and the
**two** 1.6 shelf tabs print unsupported; the mid-span ribs, the flat board
cage — back rail + 2 front tabs — and the flat wire bar are all plain walls
off the floor). Caps upside down (top face on bed) or with tree supports;
**knob crown-down** (snap peg pointing up, prints support-free). Case is
~41.5 tall; with caps ≈ 54.5 overall (knob crown at
57.5). Every part = union of closed shells; slicers merge
coplanar/overlapping shells.

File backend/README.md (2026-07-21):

# Orchestrator Pad — voice backend

The little server the pad talks to. It runs on your Mac (the same machine as
the Loom daemon, reachable over your LAN or tailnet) and turns a held-to-talk
recording into a spoken answer:

```
pad mic ──16 kHz PCM──▶  /voice  ──▶  STT  ──▶  brain  ──▶  TTS  ──▶  16 kHz PCM ──▶ pad amp
                                    (Groq/DG)   (Loom│LLM)  (Deepgram)
```

Everything speaks **one audio format end to end — 16 kHz, 16-bit, mono PCM** —
so there's no transcoding anywhere: the mic records it, Deepgram is asked to
return it, and the amp plays it straight off the wire.

Zero npm dependencies — just Node's built-in `http`, `fetch`, and `FormData`.
Node ≥ 20.

## Setup

```bash
cd backend
cp .env.example .env      # then fill in the two keys
npm start
```

You need **two API keys** in `.env` (it's gitignored — keys never get committed):

| Key | Used for | Get it |
|---|---|---|
| `GROQ_API_KEY` | LLM (`llama-3.3-70b`), and STT if you enable Groq whisper | <https://console.groq.com/keys> |
| `DEEPGRAM_API_KEY` | TTS (`aura-2-thalia`), and STT by default (`nova-2`) | <https://console.deepgram.com/> |

On start it fails loud if either key is missing. Everything else has a sane
default (see `.env.example`), so a fresh clone runs with just those two set.

### STT provider

Speech-to-text is Deepgram `nova-2` out of the box. Groq's whisper is faster
but Groq gates audio models per-project — once you've enabled them for your
key's project, set `STT_PROVIDER=groq` and STT moves to Groq whisper. The LLM
is always Groq; TTS is always Deepgram.

### Pad auth (`PAD_TOKEN`)

Set `PAD_TOKEN` to a shared secret and the backend refuses any request that
doesn't present it (`Authorization: Bearer <token>`, checked in constant time).
Leave it empty on a trusted LAN; **set it before exposing the backend to the
internet** (Tailscale Funnel, below) — otherwise anyone who finds the URL can
spend your API keys and drive Loom.

```bash
echo "PAD_TOKEN=$(openssl rand -hex 24)" >> .env
```

Enter the same value in the pad's setup portal ("Pad token").

## The brain: Loom vs. LLM

- **`loom`** (default when the daemon is reachable): the pad drives Loom.
  Selecting an agent is a **handoff** — it locks that agent and shows up in the
  thread. A held-to-talk turn is posted as a **message** to that agent; the
  backend polls the daemon's events and speaks the agent's reply. Real work
  takes a while, so if the agent is still going after `LOOM_REPLY_TIMEOUT_MS`
  the pad hears "sent — check the thread" instead of hanging.
- **`llm`**: a standalone Groq chat, no Loom. Good for a desk toy or when the
  daemon isn't running. The pipeline is otherwise identical.

It auto-detects at startup: if `LOOM_URL` (default `http://127.0.0.1:7420`)
answers, it uses Loom; otherwise it falls back to the LLM. Force it with
`BRAIN=loom` or `BRAIN=llm`.

When the backend runs on the same machine as the daemon it bootstraps the
admin token over loopback — **no token to configure**. Set `LOOM_TOKEN` only
for a remote daemon over the tailnet.

## Endpoints

| Method + path | Body | Returns |
|---|---|---|
| `GET /health` | — | JSON: `brain`, selected `agent`, `agents`, `models` |
| `POST /select` | `{"agent":"claude-code"}` | locks the agent in Loom (a handoff) |
| `POST /voice?agent=…` | raw PCM (16 kHz/16-bit/mono) | PCM reply body + `X-Transcript` / `X-Reply` / `X-Agent` headers |
| `GET /speak?text=…` | — | PCM of the spoken text (the "connected" cue, telnet `say`) |

`/voice` and `/speak` return the reply with a **`Content-Length`** (not chunked)
on purpose: the ESP32 reads the raw body stream, and chunk markers would
corrupt the PCM.

## Tests

```bash
npm test            # unit + integration + loom  (12 tests)
npm run test:unit   # WAV framing, isWav, config  — no network
npm run test:voice  # audible end-to-end on macOS (uses `say` + `afplay`)
```

- **unit** — `pcmToWav` header bytes, `isWav` boundaries, config loading.
- **integration** — spawns the server with `BRAIN=llm`, synthesizes a real
  16 kHz WAV with macOS `say`, POSTs it to `/voice`, and asserts the round trip
  (e.g. "what's the capital of France" → a reply containing "Paris").
- **loom** — skips gracefully when no daemon is up.

`npm run test:voice` is the fun one: it speaks a prompt, sends it, and plays the
answer out loud — the whole pipeline without the hardware.

## Pointing the pad at it

The pad's setup portal asks for a **backend URL**. Two ways to reach the Mac —
the scheme in the URL is what tells the firmware which transport to use.

### Same Wi-Fi — a LAN URL (simplest)

```bash
ipconfig getifaddr en0      # your Mac's LAN IP, e.g. 192.168.1.20
```

Enter `http://192.168.1.20:8080` in the portal. The server binds `0.0.0.0`, so
anything on the same network reaches it. No token needed on a trusted LAN.

> **Not the `tailscale ip` (`100.x`).** A bare ESP32 isn't a tailnet node, so it
> can't route to a `100.x` address even on the same Wi-Fi. Use the LAN IP here,
> or Funnel below for a public URL.

### Anywhere — Tailscale Funnel (a public HTTPS URL)

Funnel puts the backend behind a public `https://<machine>.<tailnet>.ts.net`
URL that the pad reaches over TLS from *any* network. **Set `PAD_TOKEN` first** —
Funnel is public-internet-facing.

```bash
# one-time: enable HTTPS + Funnel for this machine in the admin console
#   https://login.tailscale.com/admin/dns        (enable MagicDNS + HTTPS)
#   https://login.tailscale.com/admin/acls       (add the "funnel" nodeAttr)
tailscale up                       # if not already logged in
tailscale funnel 8080              # proxy public :443 → localhost:8080
tailscale funnel status            # prints your https://<machine>.<tailnet>.ts.net URL
```

Put that `https://…ts.net` URL and your `PAD_TOKEN` in the portal. Traffic goes
out through Tailscale's relay and back, so the same URL works at home and away —
which is why it's the pick when the pad moves around. The firmware pins the
Let's Encrypt root (ISRG Root X1) and verifies the cert, so the token can't be
sniffed by a MITM.

> Prefer not to expose it publicly? A Tailscale **subnet router** on the pad's
> LAN keeps everything private, but needs an always-on Tailscale node there
> (a Pi, another Mac) advertising the route — more moving parts than Funnel.

## Files

| File | What |
|---|---|
| `server.mjs` | HTTP server + the routes above; `think()` picks Loom vs. LLM |
| `providers.mjs` | `stt()`, `llm()`, `ttsStream()`, WAV framing |
| `loom.mjs` | daemon bridge: bootstrap token, handoff, message, poll for reply |
| `config.mjs` | all config from env, with a tiny dependency-free `.env` loader |
| `test/` | unit · auth · integration · loom |
| `test-voice.mjs` | audible end-to-end harness |

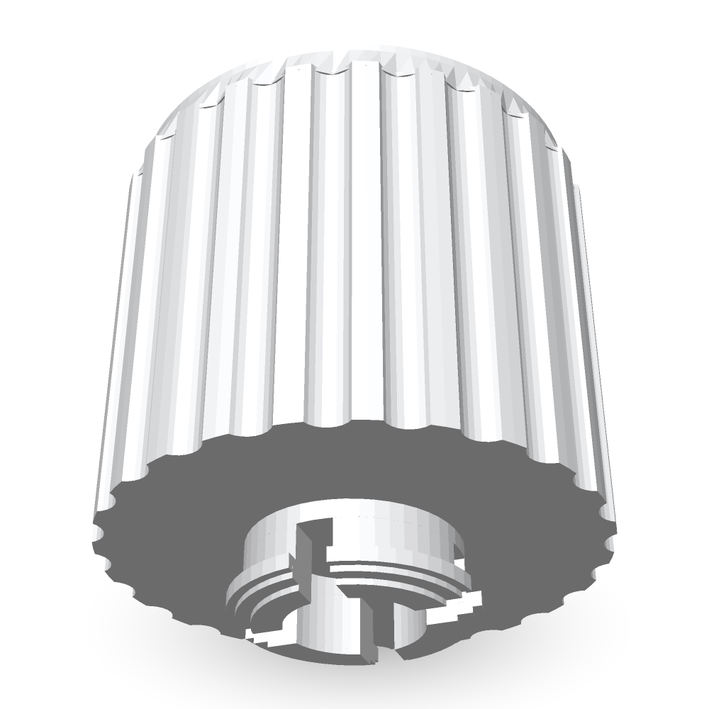
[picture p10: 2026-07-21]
docs/images/knob-peg.png

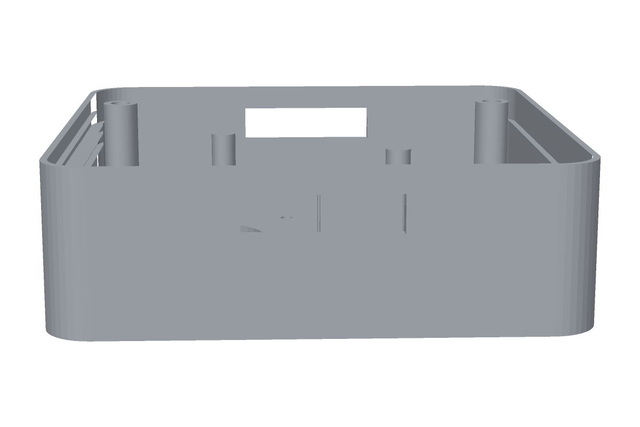
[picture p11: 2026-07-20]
docs/images/tray-right.png

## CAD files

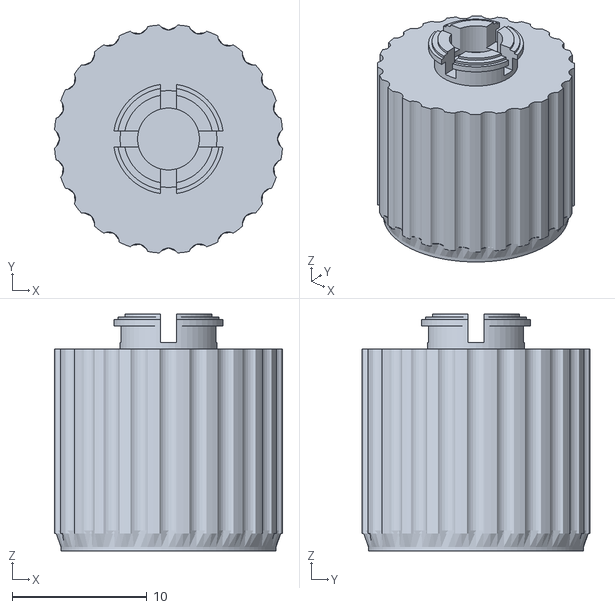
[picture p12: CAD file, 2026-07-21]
exports/knob.stl
16.9 x 16.9 x 17.6

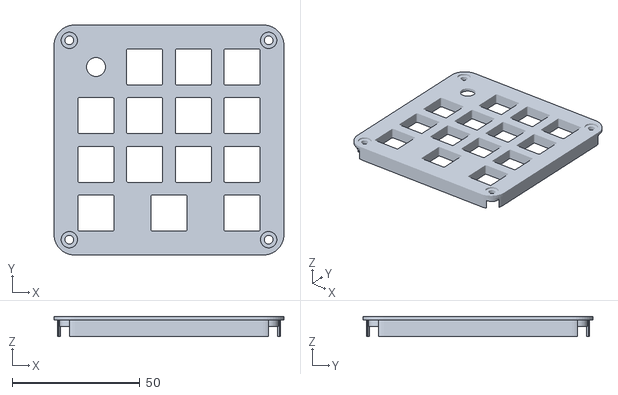
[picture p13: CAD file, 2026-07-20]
exports/plate.stl
90.0 x 90.0 x 8.00

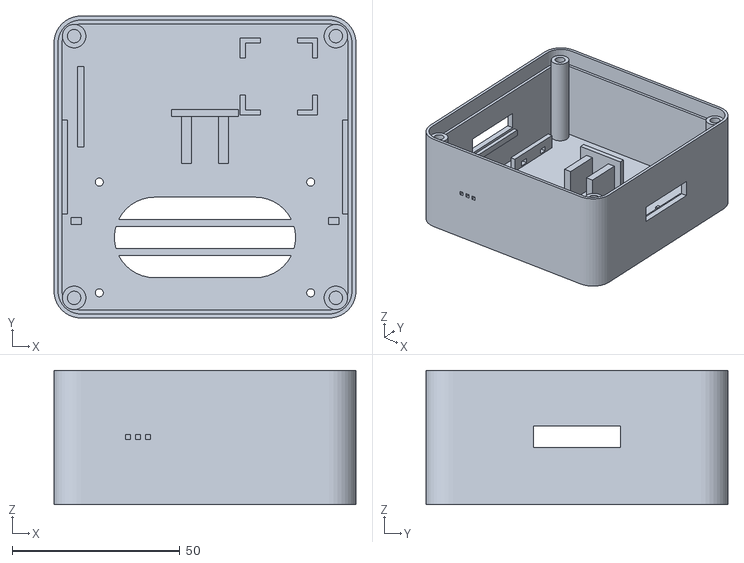
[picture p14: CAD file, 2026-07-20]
exports/tray.stl
90.0 x 90.0 x 40.0

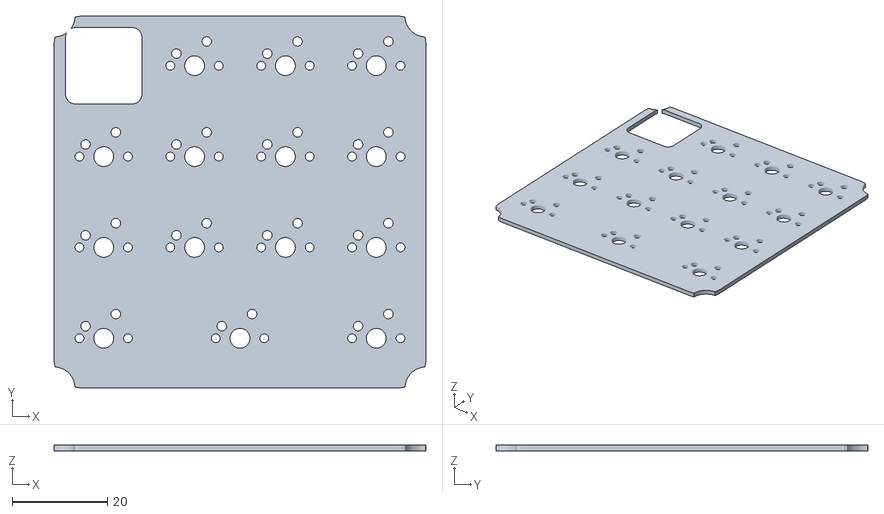
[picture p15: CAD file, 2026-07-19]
exports/switch-deck.stl
78.0 x 78.0 x 1.20

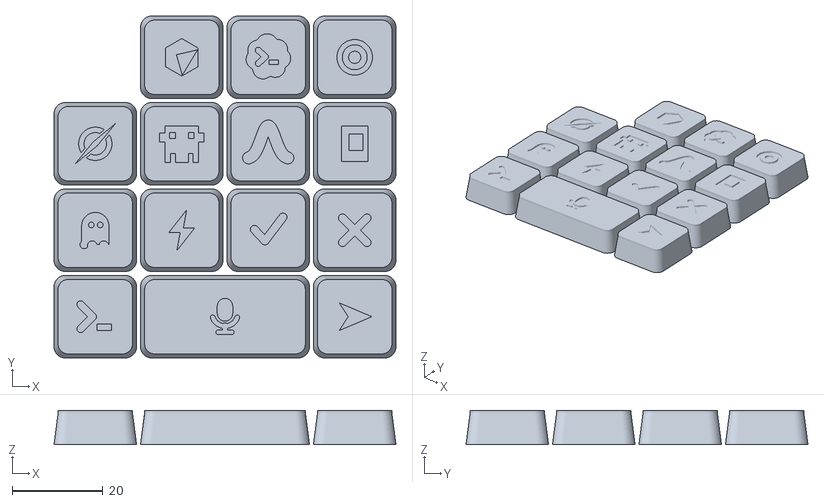
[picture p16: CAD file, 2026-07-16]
exports/caps-all.stl
75.3 x 75.3 x 7.50

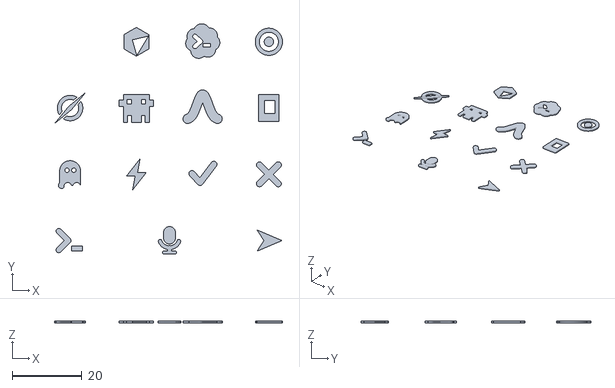
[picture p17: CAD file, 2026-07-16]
exports/legends-all.stl
65.6 x 66.2 x 0.6

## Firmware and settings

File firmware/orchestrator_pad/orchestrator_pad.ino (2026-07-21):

// ─────────────────────────────────────────────────────────────────────────────
// Orchestrator Pad — an ESP32-S3 voice + control surface for Loom.
//
// Boot flow:
//   1. If no WiFi is saved (or K1 held at power-on), raise the "LoomPad-Setup"
//      captive portal: pick your WiFi + enter the Loom backend IP, save.
//   2. Join WiFi, remember everything in flash, start the telnet debug server.
//   3. Ask the backend to speak "connected" through the amp.
//   4. Run: an agent key locks that agent in Loom (a handoff, visible in the
//      thread); hold K1 to talk → the recording is sent to that agent → its
//      spoken reply plays back.
//
// Config & wiring: config.h.  Key→agent map: agents.h.  Backend: ../backend.
// ─────────────────────────────────────────────────────────────────────────────

#include "config.h"
#include "settings.h"
#include "agents.h"
#include "matrix.h"
#include "audio.h"
#include "telnet.h"
#include "net.h"
#include "provision.h"

Matrix     matrix;
Audio      audio;
Telnet     telnet;
Net        net;
Provision  provision;
Settings   settings;

int16_t   *recBuf = nullptr;
const size_t REC_CAP = (size_t)AUDIO_SAMPLE_RATE * REC_SECONDS_MAX;
size_t     recLen = 0;
bool       recording = false;
uint32_t   recAutoStopAt = 0;          // 0 = manual (hold); else a ms deadline

String     selAgent = "";              // currently selected agent
uint8_t    selR = 0, selG = 20, selB = 0;

inline void led(uint8_t r, uint8_t g, uint8_t b) { rgbLedWrite(STATUS_LED, r, g, b); }
inline void ledReady() { led(selAgent.length() ? selR : 0, selAgent.length() ? selG : 20, selAgent.length() ? selB : 0); }

// ── recording ────────────────────────────────────────────────────────────────
void startRecording(uint32_t autoStopMs = 0) {
  if (recording) return;
  if (!selAgent.length()) {
    telnet.logf("  select an agent first (press an agent key)\n");
    audio.beep(300, 120);
    return;
  }
  recLen = 0;
  recording = true;
  recAutoStopAt = autoStopMs ? millis() + autoStopMs : 0;
  led(70, 0, 0);                        // red = recording
  audio.beep(1200, 70);
  telnet.logf("  ● recording for %s…\n", selAgent.c_str());
}

void stopAndSend() {
  if (!recording) return;
  recording = false;
  led(70, 40, 0);                       // amber = thinking
  audio.beep(700, 70);
  float secs = (float)recLen / AUDIO_SAMPLE_RATE;
  if (recLen < AUDIO_SAMPLE_RATE / 4) { // < 0.25 s
    telnet.logf("  … too short (%.2fs), ignored\n", secs);
    ledReady();
    return;
  }
  telnet.logf("  … captured %.1fs, sending to %s\n", secs, selAgent.c_str());
  String heard, said;
  bool ok = net.talk(recBuf, recLen, selAgent, audio, heard, said);
  if (ok) {
    telnet.logf("  heard: %s\n  said:  %s\n", heard.c_str(), said.c_str());
    ledReady();
  } else {
    telnet.logf("  ✗ voice request failed (backend at %s?)\n", settings.backendUrl);
    audio.beep(300, 220);
    led(80, 0, 0);
  }
}

// ── keys ─────────────────────────────────────────────────────────────────────
// Friendly spoken form of an agent id (the caps read better out loud).
String spokenName(const String &id) {
  if (id == "claude-code") return "Claude";
  if (id == "grok-code")   return "Grok";
  if (id == "opencode")    return "Open Code";
  if (id == "antigravity") return "Antigravity";
  if (id == "codex")       return "Codex";
  if (id == "kiro")        return "Kiro";
  return id;
}

void selectAgent(const KeyBind &kb) {
  selAgent = kb.agent;
  selR = kb.r; selG = kb.g; selB = kb.b;
  led(selR, selG, selB);
  telnet.logf("  ▸ selected %s\n", selAgent.c_str());
  // Lock it in the backend, then say the name aloud. Only speak if the select
  // reached the backend (else net.speak would stall waiting on a dead server).
  if (net.select(selAgent))
    net.speak(String("Selected ") + spokenName(selAgent), audio);
  else
    telnet.logf("    (select didn't reach the backend)\n");
}

void onKey(uint8_t r, uint8_t c, bool pressed) {
  const KeyBind &kb = keyAt(r, c);
  if (pressed)   // diagnostic: raw position + current mapping, for remapping the KEYMAP
    telnet.logf("  [KEY] row=%u col=%u  currently=%s\n", r, c,
                kb.role == ROLE_MIC ? "MIC" : (kb.agent ? kb.agent : "unbound"));
  if (kb.role == ROLE_MIC) {
    if (pressed) startRecording();
    else         stopAndSend();
  } else if (kb.role == ROLE_AGENT && pressed) {
    selectAgent(kb);
  } else if (pressed) {
    telnet.logf("  %s (unbound)\n", matrix.name[r][c]);
  }
}

// ── telnet commands ──────────────────────────────────────────────────────────
void onTelnetCommand(const String &line) {
  String cmd = line; cmd.toLowerCase();
  if (cmd == "help") {
    telnet.println("help · status · ip · heap · agent · select <a> · say <t> · talk · url <u> · token <t> · reset-wifi · reboot");
  } else if (cmd == "status") {
    telnet.logf("wifi %s  ip %s  rssi %ddBm  heap %u  psram %u\n",
                WiFi.isConnected() ? "up" : "down", WiFi.localIP().toString().c_str(),
                WiFi.RSSI(), ESP.getFreeHeap(), ESP.getFreePsram());
    telnet.logf("backend %s  (%s, token %s)  · selected: %s\n",
                settings.backendUrl, settings.secure() ? "https" : "http",
                settings.padToken[0] ? "set" : "none",
                selAgent.length() ? selAgent.c_str() : "(none)");
  } else if (cmd == "map") {
    for (uint8_t r = 0; r < MATRIX_ROWS; r++) {
      char line[128] = "";
      for (uint8_t c = 0; c < MATRIX_COLS; c++) {
        const KeyBind &k = keyAt(r, c);
        const char *nm = (k.role == ROLE_MIC) ? "MIC" : (k.agent ? k.agent : "-");
        strncat(line, nm, sizeof(line) - strlen(line) - 4);
        strncat(line, " | ", sizeof(line) - strlen(line) - 1);
      }
      telnet.logf("  r%u: %s\n", r, line);
    }
  } else if (cmd == "ip") {
    telnet.println(WiFi.localIP().toString());
  } else if (cmd == "heap") {
    telnet.logf("heap %u  psram %u\n", ESP.getFreeHeap(), ESP.getFreePsram());
  } else if (cmd == "agent") {
    telnet.println(selAgent.length() ? selAgent : String("(none)"));
  } else if (cmd.startsWith("select ")) {
    selAgent = line.substring(7); selAgent.trim();
    telnet.logf("selected %s\n", selAgent.c_str());
    net.select(selAgent);
  } else if (cmd.startsWith("say ")) {
    String t = line.substring(4);
    telnet.logf("speaking: %s\n", t.c_str());
    if (!net.speak(t, audio)) telnet.logf("  speak failed\n");
  } else if (cmd == "talk") {
    telnet.logf("hands-free talk (%dms)…\n", TELNET_TALK_MS);
    startRecording(TELNET_TALK_MS);
  } else if (cmd.startsWith("url ")) {
    String u = line.substring(4); u.trim();          // original case — URLs matter
    settings.set(u.c_str(), settings.padToken);      // repoint backend, keep token + WiFi
    telnet.logf("backend URL → %s\n", settings.backendUrl);
    String brain;
    if (net.health(brain)) {
      telnet.logf("  ✓ reachable (brain=%s)\n", brain.c_str());
      net.speak("Backend connected.", audio);
    } else {
      telnet.logf("  ✗ not reachable yet — check the IP/port and that the backend is running\n");
    }
  } else if (cmd.startsWith("token ")) {
    String t = line.substring(6); t.trim();
    settings.set(settings.backendUrl, t.c_str());
    telnet.logf("pad token %s\n", t.length() ? "set" : "cleared");
  } else if (cmd == "reset-wifi") {
    telnet.println("wiping WiFi + settings, rebooting into the portal…");
    provision.resetWifi(); Settings::erase();
    delay(400); ESP.restart();
  } else if (cmd == "reboot") {
    telnet.println("rebooting…"); delay(200); ESP.restart();
  } else {
    telnet.println("unknown — 'help'");
  }
}

// K1 held at power-on? (used to force re-provisioning). Reads the matrix raw.
bool talkKeyHeldAtBoot() {
  digitalWrite(COL_PINS[TALK_COL], LOW);
  delayMicroseconds(20);
  bool held = digitalRead(ROW_PINS[TALK_ROW]) == LOW;
  digitalWrite(COL_PINS[TALK_COL], HIGH);
  return held;
}

// ── lifecycle ────────────────────────────────────────────────────────────────
void setup() {
  Serial.begin(115200);
  uint32_t s = millis(); while (!Serial && millis() - s < 1200) {}
  led(0, 0, 60);                        // blue = booting

  matrix.begin();
  if (!audio.begin()) Serial.println("!! audio init failed");
  recBuf = (int16_t *)ps_malloc(REC_CAP * sizeof(int16_t));
  if (!recBuf) Serial.println("!! PSRAM alloc failed — enable Tools → PSRAM: OPI PSRAM");

  settings.load();
  net.begin(&settings);

  bool forcePortal = talkKeyHeldAtBoot();
  if (forcePortal) {
    Serial.println("K1 held → re-provisioning");
    provision.resetWifi();
    led(60, 0, 60);                     // magenta = portal
  } else {
    led(0, 40, 40);                     // cyan = connecting / portal
  }

  Serial.printf("provisioning… (join \"%s\" if the portal opens)\n", PORTAL_AP_NAME);
  bool up = provision.run(settings);    // blocks in the portal until configured

  if (!up) {
    Serial.println("!! WiFi not connected");
    led(80, 0, 0);
    return;                             // loop() will still scan keys / poll
  }

  Serial.printf("WiFi up: %s\n", WiFi.localIP().toString().c_str());
  telnet.begin(TELNET_PORT);
  telnet.onCommand(onTelnetCommand);
  Serial.printf("telnet:  telnet %s %u\n", WiFi.localIP().toString().c_str(), TELNET_PORT);
  Serial.printf("backend: %s  (token %s)\n", settings.backendUrl, settings.padToken[0] ? "set" : "none");

  // Announce we're up — through the amp, from the backend's TTS.
  led(0, 40, 0);                        // green = ready
  String brain;
  if (net.health(brain)) {
    Serial.printf("backend ok (brain=%s)\n", brain.c_str());
    if (!net.speak("Loom pad connected.", audio)) audio.beep(1320, 120);
  } else {
    Serial.println("!! backend not reachable — check the IP in the portal (reset-wifi to change)");
    audio.beep(880, 60); audio.beep(660, 120);   // fell-back chime
  }
  ledReady();
  Serial.println("Ready. Press an agent key, then hold K1 to talk.");
}

void loop() {
  matrix.scan(onKey);
  telnet.poll();

  if (recording && recBuf) {
    int16_t block[256];
    size_t n = audio.readMic(block, 256);
    for (size_t i = 0; i < n && recLen < REC_CAP; i++) recBuf[recLen++] = block[i];
    if (recLen >= REC_CAP) { telnet.logf("  (max length)\n"); stopAndSend(); }
    else if (recAutoStopAt && millis() >= recAutoStopAt) stopAndSend();
  }
}

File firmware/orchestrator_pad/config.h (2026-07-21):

#pragma once
// ─────────────────────────────────────────────────────────────────────────────
// Board + wiring for the ESP32-S3 macropad. Only fixed hardware facts live here;
// WiFi and the backend address are provisioned at runtime through the captive
// portal (see provision.h) and kept in NVS (see settings.h) — no recompile to
// change networks. (No potentiometer on this build; the dial code is gone.)
// ─────────────────────────────────────────────────────────────────────────────

// ---- 4×4 matrix ----
#define MATRIX_ROWS 4
#define MATRIX_COLS 4
static const uint8_t ROW_PINS[MATRIX_ROWS] = {10, 11, 12, 13};
static const uint8_t COL_PINS[MATRIX_COLS] = {18, 17, 8, 14};  // columns reversed to match the wiring

// ---- Mic: INMP441 (I2S RX) ----   VDD→3V3, GND→GND, L/R→GND
#define MIC_SCK 5
#define MIC_WS  4
#define MIC_SD  6

// ---- Amp: MAX98357A (I2S TX) ----  Vin→3V3, SD→3V3 (enable), GND→GND
#define SPK_BCLK 15
#define SPK_LRC  16
#define SPK_DIN  7

// ---- Audio: the one format the whole system speaks ----
#define AUDIO_SAMPLE_RATE 16000     // 16 kHz, 16-bit, mono — matches the backend
#define REC_SECONDS_MAX   12        // hold-to-talk ceiling; sizes the PSRAM buffer

// ---- The push-to-talk key (row/col). Also the "reset provisioning" key: hold
//      it while powering on to wipe saved WiFi and re-open the portal. ----
#define TALK_ROW 0
#define TALK_COL 2                  // mic key's RAW matrix position (K13, mirrored → row0/col2)

// ---- Backend URL default (editable in the captive portal, saved to NVS) ----
// LAN:    http://<your-mac-ip>:8080
// Remote: https://<machine>.<tailnet>.ts.net   (Tailscale Funnel — needs a token)
#define DEFAULT_BACKEND_URL "http://192.168.1.100:8080"

// ---- Telnet debug console: fixed port (not in the portal — it's not the
//      backend, just a log/command line you reach with `telnet <pad-ip>`). ----
#define TELNET_PORT 23

// ---- Captive-portal access point shown during provisioning ----
#define PORTAL_AP_NAME "LoomPad-Setup"
#define PORTAL_AP_PASS ""           // "" = open AP; set 8+ chars for a locked one

// ---- Onboard status LED: WS2812 addressable RGB on GPIO 48 ----
#define STATUS_LED 48

// ---- Hands-free telnet `talk` test: record this many ms then send ----
#define TELNET_TALK_MS 4000

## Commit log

2026-07-16 orchestrator-pad v0.1 — printable enclosure, keycaps, knob
    Parametric Python CAD (numpy + shapely, no CSG) for an ESP32-S3 macropad
    that orchestrates coding agents: 5 agent keys (Codex/Claude/Antigravity/
    OpenCode/Kiro), run/approve/reject, 2u hold-to-talk voice bar, EC11 effort
    dial (low..ultracode). Includes STL/GLB exports, fit audits against the
    DevKitC-1 drawing, and MANIFEST.
    [caps-all.stl, knob.stl, plate.stl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]
2026-07-16 v2: logo keycaps, +3.5mm case for DevKitC clearance, USB mating relief, README with renders
    - Logo glyph caps: Claude Code pixel-pal, Antigravity arch, opencode frame,
    Kiro ghost, Cursor cube (new key on r0c1; Codex keeps X) — debossed 0.6,
    negative space stays raised
    - Case raised to 17.5/19.0: switch undersides clear the WROOM can (0.60),
    UART relief pocket + forward board stop, snug 87.3 skirt, knob EC11 nut
    recess, reset pinhole dropped
    - audit_fit + audit_post_can: all acceptance checks PASS, all shells watertight
    - README: hero/top/exploded/parts renders (cad/render_docs.py — pure numpy
    z-buffer rasterizer with cavity AO), deck table, BOM, print guide
    - v1 letter-cap vers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
    [caps-all.stl, knob.stl, plate.stl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]
2026-07-16 v2.1: Grok + Codex keys, two-color legend infills
    - Grok circle-slash replaces the X at r1c0; Codex cloud->_ takes r0c2 —
    seven agent keys (Grok, Codex, Claude Code, Antigravity, opencode, Kiro,
    Cursor) + one preset
    - Every glyph now ships a flush 0.6mm legend infill as a separate item:
    white on colored caps, charcoal on white caps (partlib key_layout legend
    field); new exports/legends-all.stl pre-aligned with caps-all.stl for
    AMS/MMU or single-swap two-color printing
    - README/SPEC: new deck table, two-color print guide, colors
    [caps-all.stl, legends-all.stl]
2026-07-16 docs: version scheme — v1/v2 branches, main is v3
2026-07-19 v4: fat base — 28mm component bay for real hardware
    - Tray 17.5 -> 28.0: interior is now a component bay sized from the user's
    actual parts (dual-USB-C ESP32-S3 clone WITH factory headers, MAX98357A
    amp, 72x42 cavity speaker, round I2S mic, jumper wiring)
    - Down-firing speaker bay: 54x24 floor grille (3 slots) + 4x M2.5 pilots,
    flange-on-floor, needs >=3mm feet
    - Board bridge: back shelf + front bridge + 4 locator posts seat the board
    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
    [plate.stl, tray.stl]
2026-07-19 v5: donor-style switch sockets — solder-through footprint floors
    - Every MX cutout gets a pocket box under the plate: 1.6 walls caging the
    switch body, 1.2 socket floor at Z 24.5 (plate top - 5.0) so the base
    seats fully while the clips engage the 1.5 plate
    - Floors carry the MX footprint (post 4.3, contacts 2.8 at -3.81/+2.54 and
    +2.54/+5.08, 5-pin legs 2.0): the two metal pins protrude 2.1 below the
    floor — solder the matrix straight to them, PCB-style
    - Corner sockets notched around the screw towers (Ø8.8 keep-out, audited)
    - audit_fit section 12: seat height, pin protrusion, footprint holes,
    tower clearance — ALL CLEAR; plate now 39 shells, watertight
    - README: plate-und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
    [plate.stl]
2026-07-19 v5.1: fix unprintable socket floors — flat-printed switch deck
    The v5 in-plate socket floors became 14mm mid-air bridges with holes when
    the plate printed flipped (floating regions -> garbage supports inside
    every pocket). Fix:
    - Socket walls now stop at the MX seat plane (Z 24.5): flipped plate is
    pure vertical walls — zero bridges, zero floating regions, no supports
    - Footprints move to a new part, the switch deck: flat 78x78x1.2 sheet
    with all 14 MX clusters (post 4.15 snug, contacts 2.0, legs 1.85 snug),
    EC11 cutout, tower notches; prints flat on the bed, friction-fits onto
    the switch posts/legs from below, seats on the wall rims; pins still
    protrude 2.1 for direct solderi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
    [plate.stl, switch-deck.stl]
2026-07-20 v6: USB moves to the side walls — rotated, reversible board bay
    The charging port exited the back wall; it should come out the right or the
    left. That means the board itself turns 90 degrees, so the whole bay was
    rebuilt around it:
    - TWO USB windows, one per side wall (26 wide in Y, Z 17.0-23.5), replacing
    the single back window; the back wall is solid again
    - Board now runs along X and the bay is mirror-symmetric, so it installs
    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
    [plate.stl, tray.stl]
2026-07-20 v7: fatter 40mm case, cylindrical bay posts removed
    The user needs more room and wants nothing free-standing in the bay.
    - Case 28 -> 40mm tall (+12 shift of the whole lid stack: plate 40/41.5,
    caps 47.0, knob 42.5, ledge 33.5, boss tops 31.5/37.5). ~24mm of open
    headroom above the board now (was ~10)
    - Removed the 4 cylindrical locator posts + 2 cylindrical wire posts.
    Board is caged by flat features instead: a back guide rail (Y 15.1-17.1,
    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
    [plate.stl, tray.stl]
2026-07-20 feat(firmware): provisioning + agent-select + hold-to-talk, end-to-end
    The ESP32-S3 build with no potentiometer. Boot into a WiFiManager captive
    portal ("LoomPad-Setup"): pick WiFi, enter the Loom backend IP + telnet
    port, save — persisted in NVS so it only happens once (hold K1 at power-on
    to re-provision). On connect it starts a telnet debug server and asks the
    backend to speak "connected" through the amp.
    Run loop: an agent key (K2..K7) locks that agent in Loom via the backend
    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
2026-07-20 docs: firmware + backend READMEs, and wire them into the root
    Two new component READMEs for the hold-to-talk build:
    - backend/README.md — the two API keys, the STT→brain→TTS pipeline, the four
    endpoints, Loom-vs-LLM brain selection, the test suite, and how to point the
    pad at your Mac's IP.
    - firmware/README.md — full pin/wiring tables (pot removed), the as-built key
    map + LED colours, the captive-portal provisioning flow, Arduino board
    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
2026-07-21 feat(pad): reach the backend over Tailscale Funnel — HTTPS + a pad token
    "Telnet" was a mishearing of "tailnet." The pad's real target is the Mac's
    tailnet address, and to reach it from anywhere the backend goes behind a
    Tailscale Funnel (a public https://<machine>.<tailnet>.ts.net URL). That means
    TLS on the pad and auth on the backend.
    Backend:
    - optional PAD_TOKEN shared secret; every request must carry it as
    `Authorization: Bearer …` (constant-time check), else 401. Empty = trusted-LAN
    mode. Required once Funnel exposes it to the public internet.
    - test/auth.test.mjs covers the gate (no/wrong/right token, X-Pad-Token form).
    16/16 pass.
    Firmware:
    - net.h speaks HTTPS via WiFiC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
    [config.h, orchestrator_pad.ino]
2026-07-21 fix(firmware): use NetworkServer::accept() (available() is deprecated in core 3.x)
    Verified the whole sketch actually compiles: a real arduino-cli build against
    esp32 core 3.3.10 + WiFiManager 2.0.17 for esp32s3 (OPI PSRAM, USB-CDC). The
    only warning in the sketch was telnet.h calling the renamed WiFiServer method —
    fixed. Clean build now: 1.18 MB flash, 48 KB RAM.
    Also pin the board settings in the README: the default 1.3 MB app partition sits
    at ~90% with the TLS stack in; recommend Huge APP (drops to ~37%).
2026-07-21 fix(firmware): real-hardware bring-up — keycap map, row flip, voice cues
    Flashed and verified on the actual ESP32-S3 build:
    - agents.h: KEYMAP now matches the soldered keycaps (K1..K14) instead of the
    guessed layout — mic is K13, agents on their real cells.
    - config.h: ROW_PINS reversed to {13,12,11,10}; this unit reads flipped
    top-to-bottom otherwise ("180° upwards"). TALK gesture follows the mic to K13.
    - speak the agent name on select ("Selected Claude") and say "Loom pad
    connected" on boot.
    - telnet: `url <u>` / `token <t>` commands to re-point the backend without
    re-doing WiFi; `[KEY] row/col` diagnostic on each press for remapping.
    Verified live: PSRAM 8MB ok, WiFi provis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
    [config.h, orchestrator_pad.ino]
2026-07-21 feat(firmware): keytest — standalone key-matrix wiring tester
    Flash instead of the main firmware to find dead keys: scans the 4x4 matrix,
    prints each press with its (row,col), and shows a live grid of which keys have
    registered (*) vs never fired (.). No WiFi/audio — just the matrix. Serial at
    115200. Compiles clean for esp32s3 (23% flash).
2026-07-21 v7.1: mock snap-fit knob (no potentiometer) — clips into the plate + spins
    The user is mocking, not fitting an EC11. The old knob had an EC11 D-shaft
    bore, so with no encoder it had nothing to grip. Replaced with a display
    knob that attaches to the plate directly:
    - Snap-fit peg on the underside: Ø7.2 tube split by cross-slots into 4 flex
    fingers (hollow Ø4.6 core), Ø8.2 barb + stepped lead-in. Pushes through
    the plate's Ø7.4 hole, fingers compress, barb springs under -> stays on
    - Knob body rests on the plate top (Z 41.5), barb ledge 0.2 below the plate
    bottom -> spins freely with minimal wobble (mock dial for the demo)
    - Removed the EC11 D-bore + M7 nut recess; body is now sol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
    [knob.stl]
2026-07-21 fix(firmware): map keys to real wiring + `map` diagnostic; drop mirror flag
    On-hardware bring-up on the actual hand-wired matrix:
    - agents.h: KEYS_MIRRORED off — keyAt is now a plain KEYMAP[r][c] lookup (the
    mirror flag was stacking with the pin order and double-rotating). KEYMAP holds
    the full deck (cursor, codex, grok, claude, antigravity, opencode, kiro,
    accept, cancel, terminal, mic, next) with cursor/codex/mic pinned to the cells
    they actually fire — verified live: cursor→(0,1), codex→(0,2), mic→(3,2).
    - config.h: COL_PINS reversed to {18,17,8,14} to match how the columns are wired
    (grok/claude/opencode land right after this); ROW_PINS back to natural order.
    - .ino: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
    [config.h, orchestrator_pad.ino]
2026-07-21 docs: reveal animation — assembled -> exploded -> reassemble
    cad/render_video.py: pure-numpy orthographic rasterizer (reuses render_docs),
    frames rendered in parallel, encoded by ffmpeg. Deterministic 15s / 24fps /
    1000x720 reveal: slow orbit, smooth explode into the 5 print layers (tray ·
    switch-deck · plate · caps · knob) with dynamic camera pull-back, hold, and
    reassemble. Ships docs/orchestrator-pad-reveal.mp4 (1.2MB) + a light
    docs/images/reveal.gif (2.7MB) embedded at the top of the README. The full
    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
2026-07-21 fix(backend): keep /health open (exempt from PAD_TOKEN)
    Health checks — the Loom app's LoomPad pill, load balancers — must see the
    backend is up without the pad token. Everything else still requires it.
2026-07-21 docs: add the wiring diagram (circuit.png)
    Full pin-by-pin schematic — 4x4 key matrix (rows G10-G13, cols G14/G8/G17/G18),
    INMP441 mic (SCK5/WS4/SD6), MAX98357A amp (DIN7/BCLK15/LRC16) + speaker, and the
    optional pot, on an ESP32-S3-WROOM-1. Shown in the main README's firmware section
    and at the top of the firmware README's Hardware & wiring.
